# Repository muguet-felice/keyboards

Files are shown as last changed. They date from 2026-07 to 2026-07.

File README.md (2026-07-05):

# Muguet Keyboards

Firmware, source files, and documentation for Muguet keyboard projects.

## Repository structure

Each product is stored in its own folder.

Typical contents are:

- `firmware/`  
  Prebuilt firmware files.

- `source/`  
  QMK / Vial source files.

- `README.md`  
  Product-specific information.

- Setup guide PDF  
  Assembly and setup guide.

## Notes

Firmware files are intended for the products and configurations described in each product folder.

Unsupported microcontrollers, modified hardware, custom builds, and modified firmware are not officially supported.

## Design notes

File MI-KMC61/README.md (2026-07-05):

# MI-KMC61

MI-KMC61 is a 6-key macro keyboard by Muguet.

## Files

- `MI-KMC61_SetupGuide.pdf`  
  Setup guide and assembly manual.

- `QuickStart.pdf`  
  Package insert note / quick start notice.

- `firmware/`  
  Prebuilt firmware files.

- `source/`  
  QMK / Vial source files.

## Firmware

Use the latest `.hex` file in the `firmware` folder.

## Notes

This product is a DIY keyboard kit.  
Please read the setup guide before assembly, use, or firmware update.

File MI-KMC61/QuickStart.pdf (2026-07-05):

© Muguet
2026-01 版

## 6 キーマクロキーボード

# MI-KMC61

この度は本製品をお買い求めいただき、ありがとうございます。 本製品にはセットアップガイドを同封しておりません。お手数ですが、組み立てにあたり以下のサイトから、最新版の

セットアップガイドをダウンロードしてください。

GitHub：

https://github.com/muguet-felice/keyboards/tree/main/MI-KMC61

MI-KMC61_SetupGuide.pdf
最新版は上記ファイル名で公開しております。

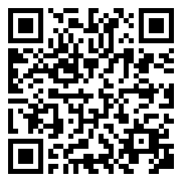
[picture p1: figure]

※本製品の組み立てにあたり、以下を別途ご用意ください。

・キーキャップ 6 個

・キースイッチ 6 個

いずれも、Cherry MX 互換のものをご用意ください

※本製品の組み立てには、以下の各種工具が必要です。
はんだ、はんだごて（電子部品向けの温度調整式のものを推奨） ニッパー（金属用）

プラスドライバー（No.1 または No.2 が適しています） キープラー（キースイッチ、キーキャップを外す場合のみ必要）

※本製品添付の Pro Micro は、ファームウェア書き込み済みです。

出荷時のファームウェアバージョンは 1.00 です。

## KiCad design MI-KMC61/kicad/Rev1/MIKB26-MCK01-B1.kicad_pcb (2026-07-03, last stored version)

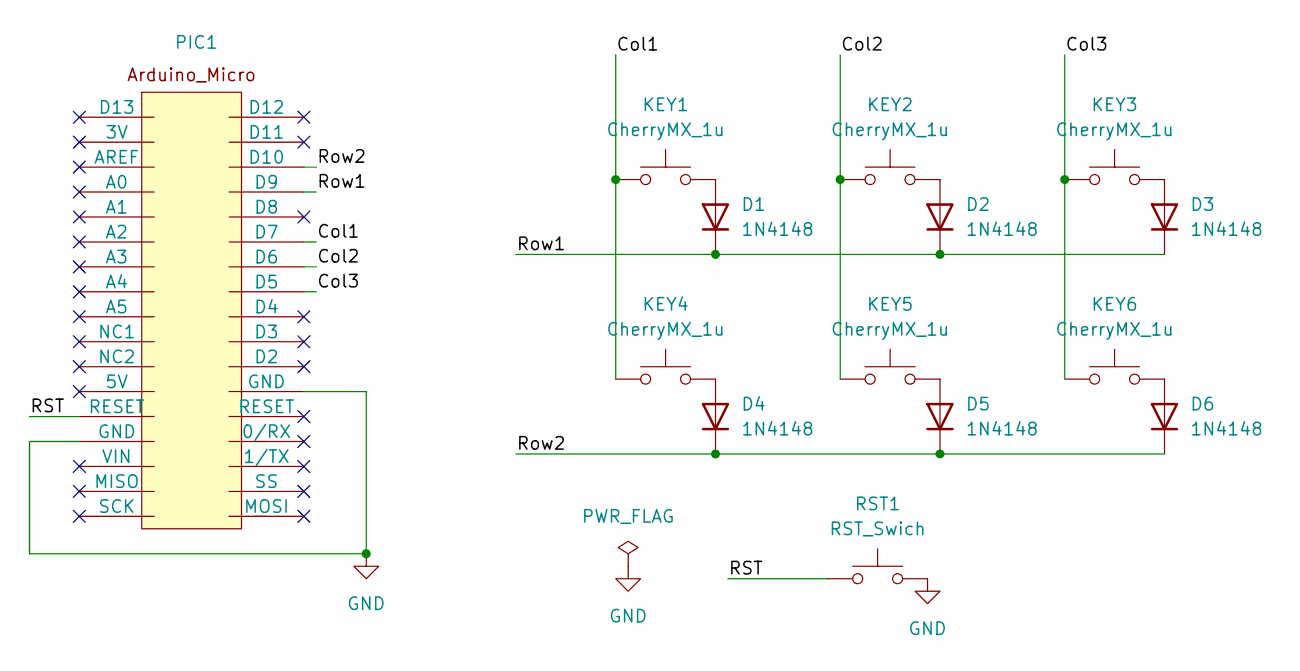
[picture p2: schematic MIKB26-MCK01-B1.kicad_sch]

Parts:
D1, D2, D3, D4, D5, D6: 1N4148; D_DO-35_SOD27_P7.62mm_Horizontal
KEY1, KEY2, KEY3, KEY4, KEY5, KEY6: CherryMX_1u; CherryMX_Solder_1u
PIC1: Arduino_Micro
RST1: RST_Swich; SW_PUSH_6mm

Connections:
/Col1: KEY1.2, KEY4.2, PIC1.D7
/Col2: KEY2.2, KEY5.2, PIC1.D6
/Col3: KEY3.2, KEY6.2, PIC1.D5
/RST: PIC1.RESET, RST1.1
/Row1: D1.1 (K), D2.1 (K), D3.1 (K), PIC1.D9
/Row2: D4.1 (K), D5.1 (K), D6.1 (K), PIC1.D10
GND: PIC1.GND, RST1.2
unnamed: D1.2 (A), KEY1.1
unnamed: D2.2 (A), KEY2.1
unnamed: D3.2 (A), KEY3.1
unnamed: D4.2 (A), KEY4.1
unnamed: D5.2 (A), KEY5.1
unnamed: D6.2 (A), KEY6.1

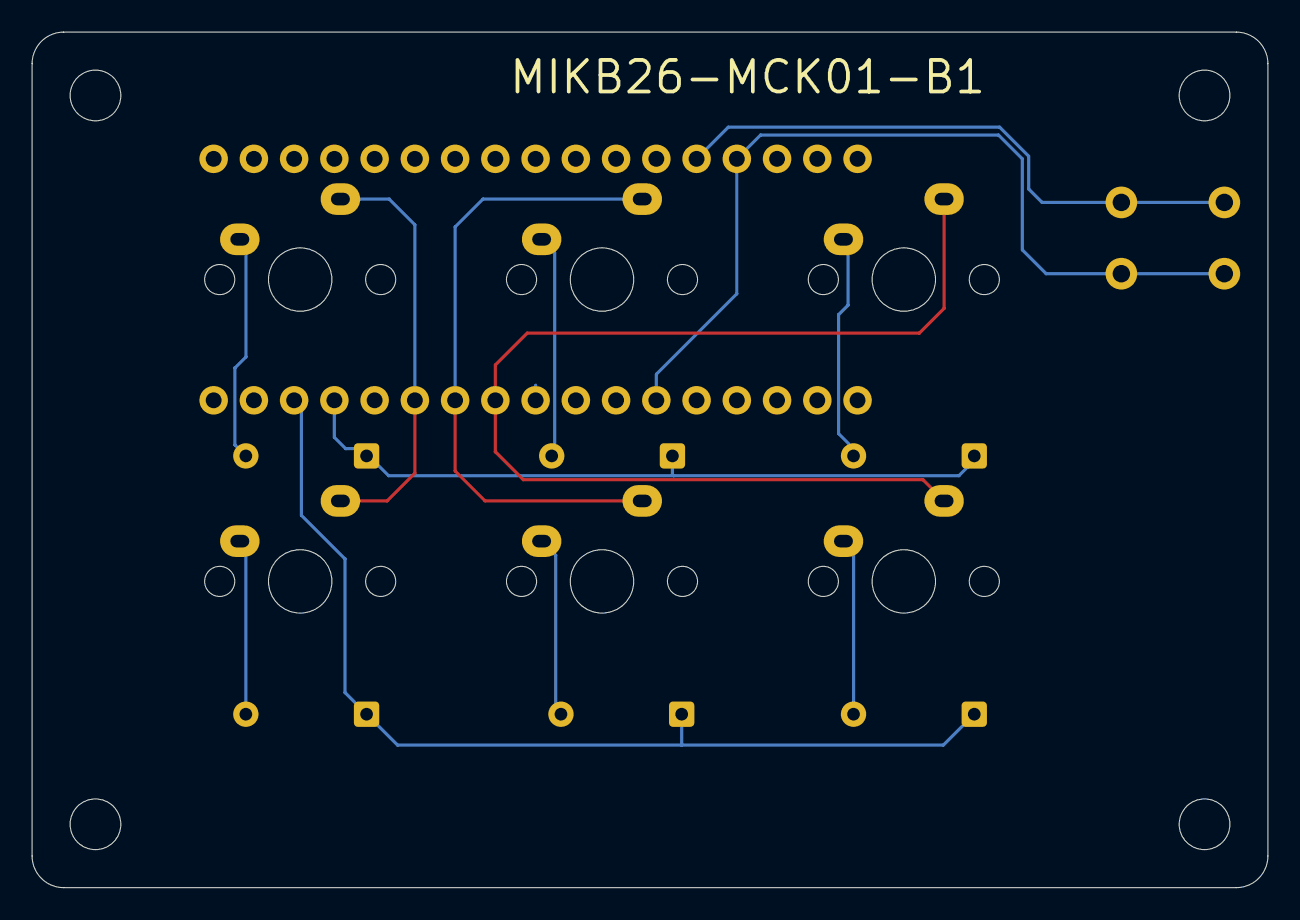
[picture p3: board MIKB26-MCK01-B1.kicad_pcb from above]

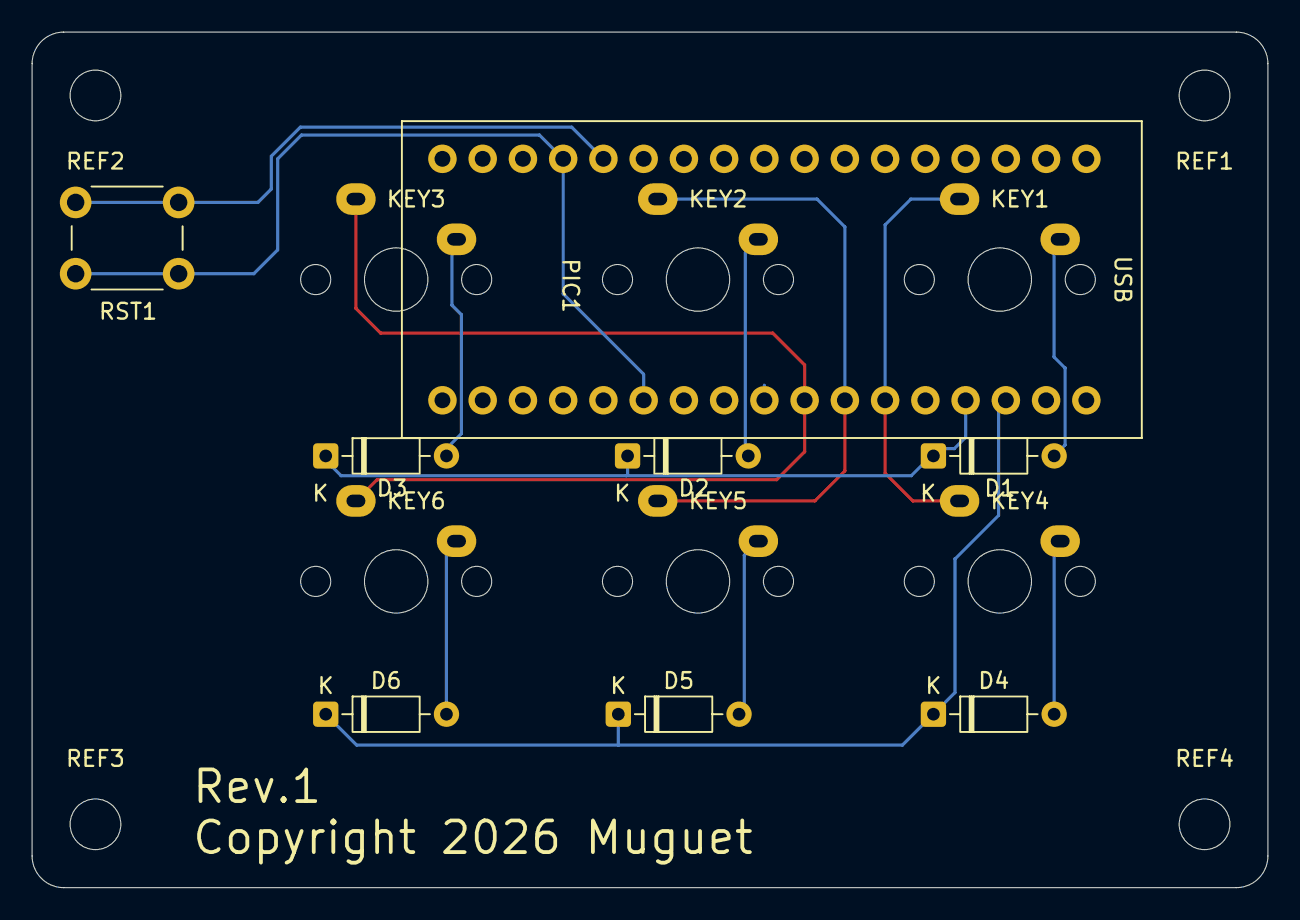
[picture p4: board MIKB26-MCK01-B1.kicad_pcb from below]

Board: 2 copper layers, 78.0 x 54.0 mm, 18 parts (8 on the bottom side), 13 nets.

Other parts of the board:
REF1, REF2, REF3, REF4: MountingHole_3.2mm_M3

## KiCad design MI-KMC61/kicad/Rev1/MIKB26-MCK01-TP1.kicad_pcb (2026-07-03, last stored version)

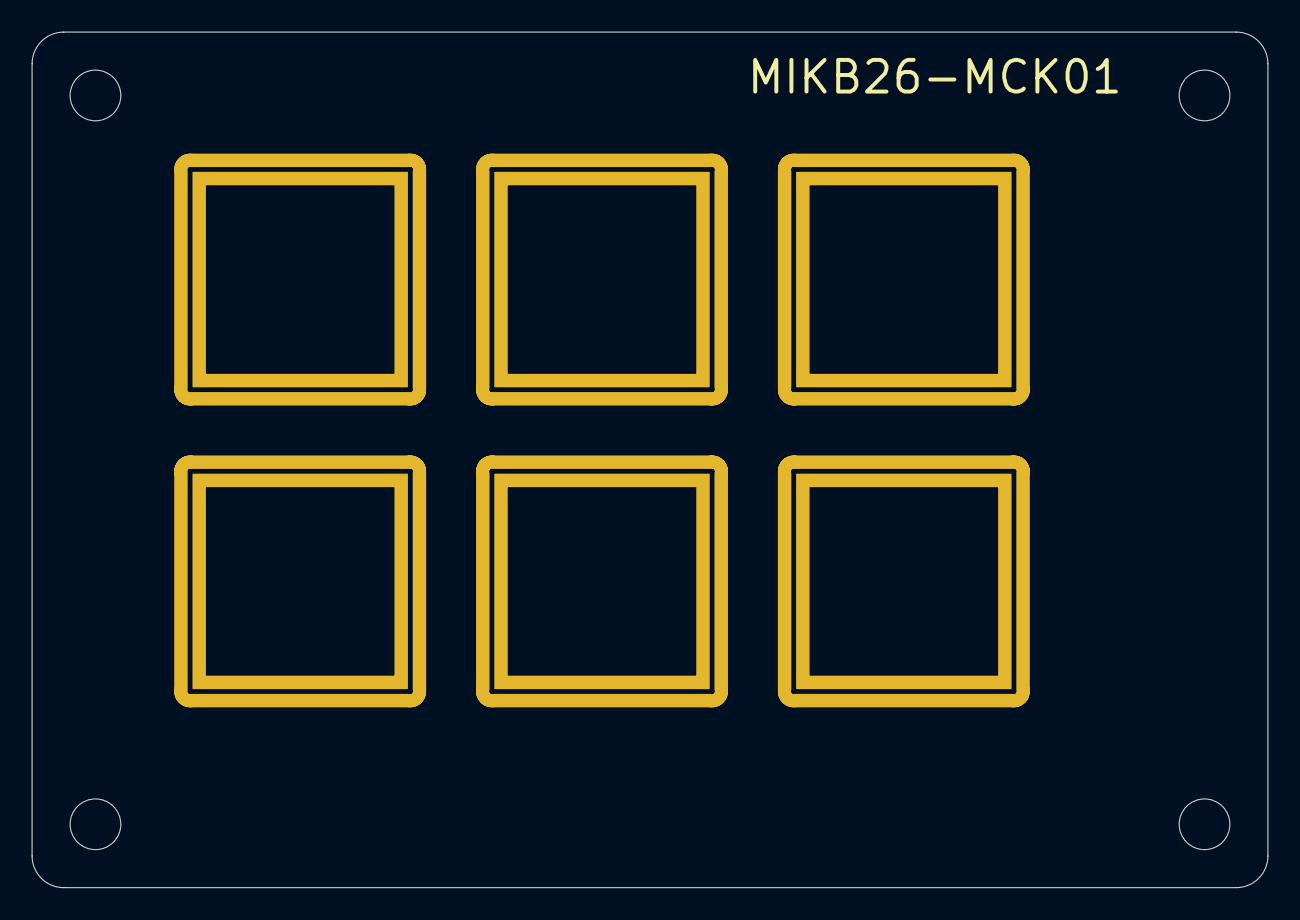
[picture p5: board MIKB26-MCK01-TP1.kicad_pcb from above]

Board: 2 copper layers, 78.0 x 54.0 mm, 10 parts (0 on the bottom side), 3 nets, no tracks yet.

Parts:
KEY1, KEY2, KEY3, KEY4, KEY5, KEY6: CherryMX_1u; SW_Hole_TH_1u
REF1, REF2, REF3, REF4: MountingHole_3.2mm_M3

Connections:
/Col1: KEY1.1 (2_2), KEY4.1 (2_2)
/Col2: KEY2.1 (2_2), KEY5.1 (2_2)
/Col3: KEY3.1 (2_2), KEY6.1 (2_2)

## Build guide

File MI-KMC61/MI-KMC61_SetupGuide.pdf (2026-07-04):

© Muguet
2026-01 版

## 6 キーマクロキーボード

# MI-KMC61

# セットアップガイド

この度は本製品をお買い求めいただき、ありがとうございます。 組み立ての前に、本セットアップガイドをよくご確認ください。 作業中も必要に応じて参照しながら、手順に沿って組み立てを進めてください。 本セットアップガイドは組み立て後も確認できるよう、お手元に保管してください。

【ご使用上の注意】
本製品は、一般的な PC 用入力機器としての個人利用を想定して設計されています。 医療、航空宇宙、運輸、軍事など、高い安全性・信頼性が要求される用途ではご使用いただけません。

本製品は、ユーザーご自身で組み立てを行うキット製品です。 組み立ての際は、本セットアップガイドをよく確認し、部品の向きや取り付け位置を間違えないよう注意し

て作業してください。

はんだ付け不良、部品の取り付け間違い、ショート、組み立て作業中の部品破損など、ユーザー作業に起 因する不具合については、原則としてサポート対象外となります。

ファームウェア更新、キーアサイン変更、マイコン交換、改造、指定外部品の使用、外部ソフトウェア・外部 サービスの利用に起因する不具合については、対応できない場合があります。

また、本製品に関連して生じたいかなる損害についても、当方は責任を負いかねます。 あらかじめご了承ください。

## 【もくじ】

## セットアップする

Step１ 付属品を確認する

Step２ 組み立てる

Step３ キーアサインを変更する

付録

ファームウェアをアップデートする

マイコンを Type-C タイプに変更する際のご注意

本製品で使える Vial®の機能

# セットアップする

## Step１ 付属品を確認する

本製品には以下の部品が付属しています。

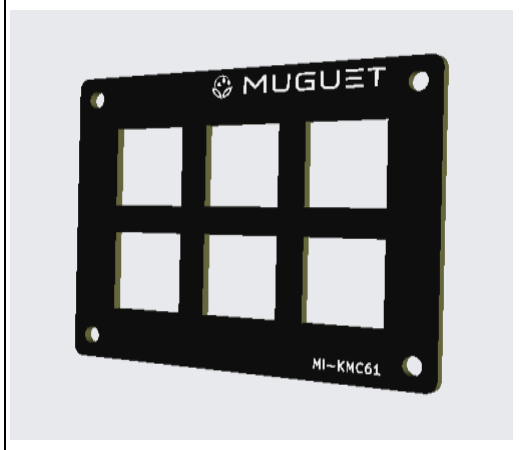
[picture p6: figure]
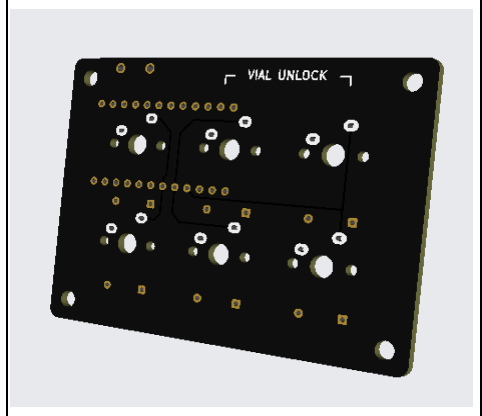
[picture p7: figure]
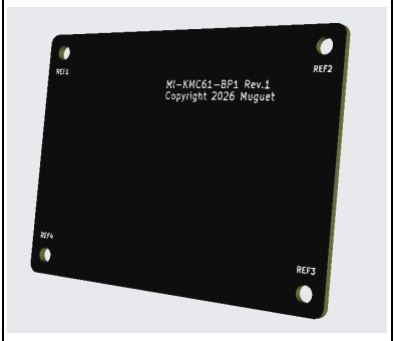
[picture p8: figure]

部品袋開封前に、すべての部品が揃っていることを確認してください。 ※部品袋開封後、または組み立て作業開始後の部品不足・破損については対応いたしかねます。
トッププレート 1 枚 | メインボード 1 枚 | ボトムプレート 1 枚

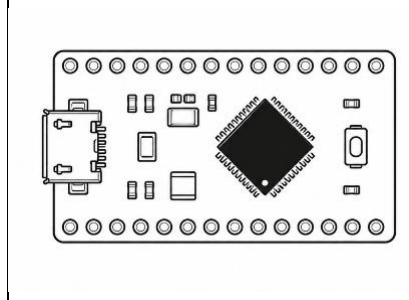
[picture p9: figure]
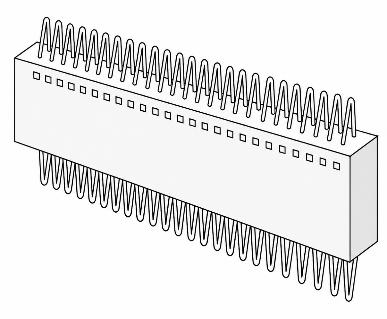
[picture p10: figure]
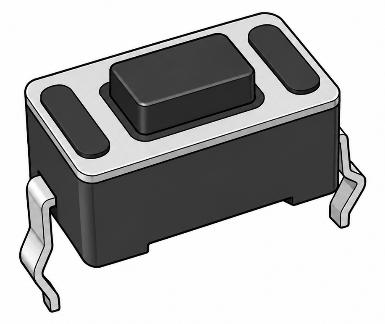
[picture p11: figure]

Pro Micro マイコン 1 枚 本セットには Type-C が同梱され ています | コンスルー 2 本 | リセットスイッチ 1 個
ネジ 10mm 4 本 5mm ４本 | 六角スペーサー 4 個 | ナイロンスペーサー 4 個

ダイオード ６本 | ゴム足 4 個 1 シート

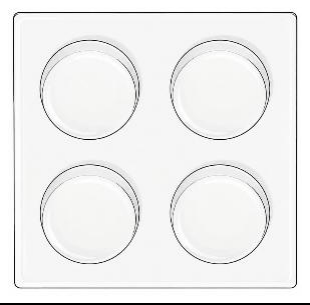
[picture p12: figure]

※上記のほかに以下が別途必要になります

・キーキャップ 6 個

・キースイッチ 6 個

いずれも、Cherry MX 互換のものをご用意ください

遊舎工房、Amazon などの EC サイトで入手可能です。お好みのタッチ、レスポンスのものをお選びくだ

さい。

※本製品の組み立てには、以下の各種工具が必要です。
はんだ、はんだごて
電子部品向けの温度調整式のものを推奨します。
温度は使用するはんだに合わせて調整してください。
ニッパー（金属用）

プラスドライバー（No.1 または No.2 が適しています）

キープラー
必須ではありませんが、キースイッチ、キーキャップを外す場合には必要になります。

【注意】はんだごてやニッパーなどによる火傷や怪我、小さなお子様による部品の誤飲などにご注意ください。 作業中に生じた火傷や怪我等について、当方は責任を負いかねます。

## Step２ 組み立てる

部品が一通りそろっていることを確認できたら、以下の手順に沿って組み立ててください。

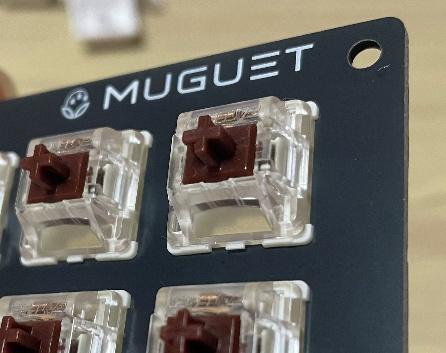
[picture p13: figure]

① トッププレートにキースイッチをはめ込む
トッププレートの表から、キースイッチを取り付けます。この時、 のロゴマークが正しく見える向きに上
下を合わせてください。
本製品では、すべてのキースイッチを同じ向き（裏面のピンが 上側）になるように取り付けてください。

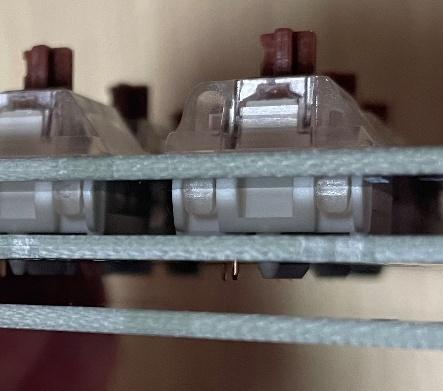
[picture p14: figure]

② 仮組して、正しく組みあがることを確認する
メインボードを、トッププレートの裏側から合わせてください。

このとき、四隅のねじ穴についている REF 番号が、すべての基 板で同じ位置になるようにしてください。
キースイッチの突起部分やピンが、メインボードの穴に正しくは まることを確認してください。確認ができたら、メインボードの表 裏、上下を把握しておいてください。

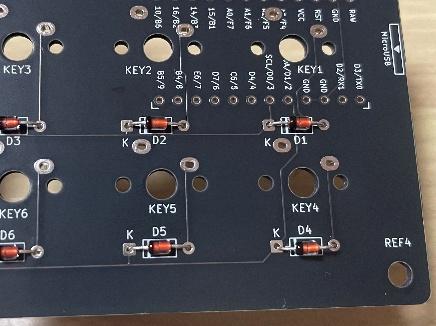
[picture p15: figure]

③ ダイオードを取り付ける
メインボードの裏面に、印字に従ってダイオードを取り付けま す。
ダイオードの黒い帯がある側を、メインボード上の K 印字側に 向けて取り付けます。
ダイオードはメインボードの裏面から取り付け、表面に飛び出し たリード線をはんだ付けしてください。はんだ付け後は飛び出し

たリード線をニッパーで短くカットしてください。

④ リセットスイッチを取り付ける
リセットスイッチを、ダイオード同様メインボードの裏面に取り付

けてください。
根本までしっかり、基板に押し付けるように差し込んでから、 はんだ付けしてください。

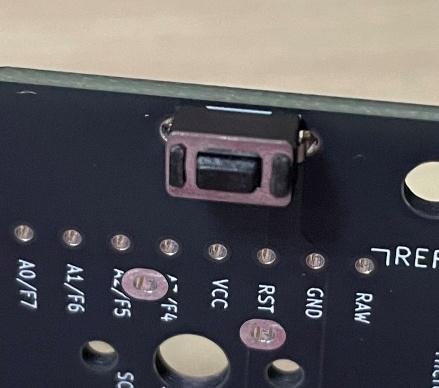
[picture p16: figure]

⑤ はんだ付けが漏れていないか、確認する
ここまでに取り付けた部品について、はんだ付け漏れがないことを確認してください。 また、ダイオードの取り付けが正しい事（黒い帯の部分が K と書かれた端子の方に向いているこ と）を確認してください。
【注意】以降の手順で、トッププレートを取り付けた後は、はんだ付けのやり直しが非常に難しくなり ます。

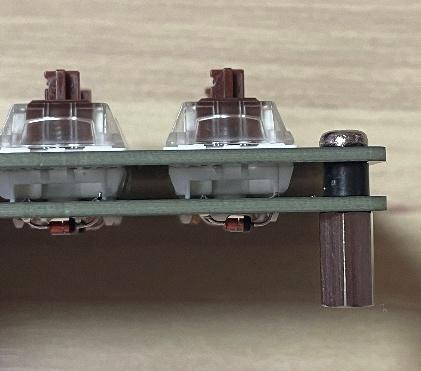
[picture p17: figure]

⑥ トッププレートを取り付ける
トッププレートを②で確認した通りにキースイッチごとメインボード に組み合わせてください。キースイッチが正しくメインボードに組

み合わさった状態で、四隅を 10mm ネジと六角スペーサーで 固定します。

この際、トッププレートとメインボードの間に、四隅のネジ穴部 分にナイロンスペーサーを合わせ、ナイロンスペーサーをネジが貫 通するようにしてください。

⑦ キースイッチをはんだ付けする

メインボード裏面から、キースイッチの金属端子をすべて、はんだ付けしてください。

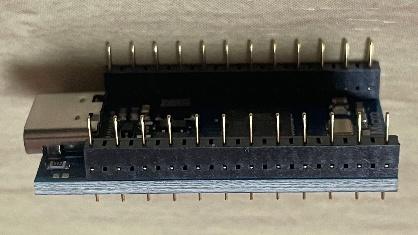
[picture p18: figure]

⑧ コンスルーを Pro Micro に取り付ける

コンスルーを Pro Micro の表側に取り付けてください。取り付

けの際は、コンスルーのプラスチック部分の側面に見える窓

が、Pro Micro 側になるようにしてください。また、窓の向きが 2 本とも同じ向きになるように取り付けてください（写真参 照）

コンスルーは Pro Micro にはんだ付けしてください。

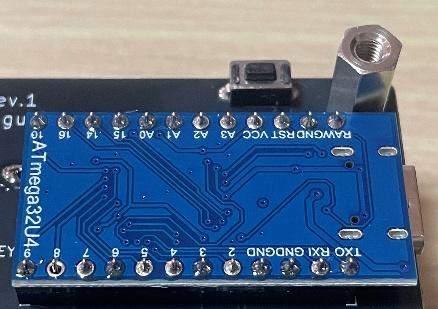
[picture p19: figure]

⑨ Pro Micro を取り付ける

メインボードに Pro Micro を根元までしっかり差し込んでくださ

い。
USB 差込口がメインボード側、かつ、メインボードの外に向くよ うに取り付けます。

Pro Micro は差し込むだけで、コンスルーのバネの力で固定さ れます。
メインボードとコンスルーははんだ付けしないでください。

⑩ ボトムプレートを取り付ける
ボトムプレートの四隅のネジ穴を六角スペーサーに合わせ、

5mm ネジで取り付けてください。
ボトムプレートは型番印字のある面をメインボード側に向けて 取り付けます。

また、各ネジ穴の REF1～REF4 の印字が、メインボード側の 印字位置と一致するように取り付けます。

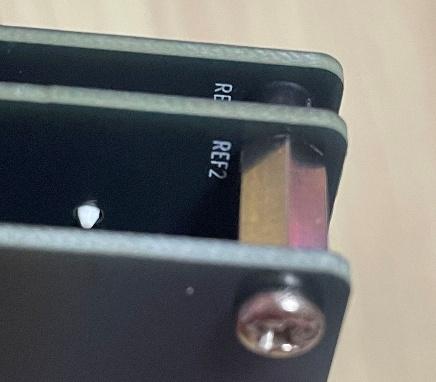
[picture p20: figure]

⑪ USB ケーブルで PC 本体と接続してください。USB ケーブルは USB 規格 2.0 以上のデータ通信がで きるものが必要です。
【注意】充電専用ケーブルでは動作しません。
テキストエディタなどを開き、すべてのキーを順に押下して、正常に動作することを確認してください。

デフォルトのキーアサインは、「Step３ キーアサインを変更する」をご確認ください。

## Step３ キーアサインを変更する

デフォルトのキー配置は以下のようになっています。

本製品は Vial®に対応しています。

Vial®の Web 版設定ツールを使用することで、キーアサインの変更をブラウザ上で行うことができます。 ※変更したキーアサインは本製品の Pro Micro 内に保存されます。 設定変更後に通常使用する際は、インターネットや Vial®サイトへの接続は不要です。

Vial®を使ったキーアサインの変更は以下の手順で行います。

① Vial®に接続する
キーボードを接続した PC でブラウザを開き、以下の URL に接続します。

https://vial.rocks/

「Start Vial」という大きなボタンが表示されれば成功です。

② キーボードを選択する

Start Vial ボタンをクリックすると、キーボードデバイスリストが表示されます。

本製品の場合、「MI-KMC61」を選択し、「接続」をクリックしてください。

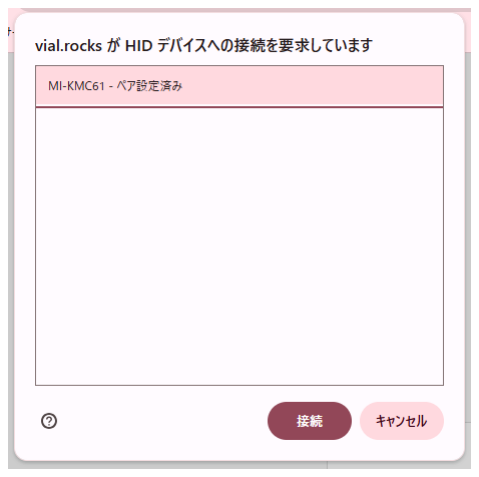
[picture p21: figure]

③ キーアサインを変更する
現在のキーアサインが表示されます。

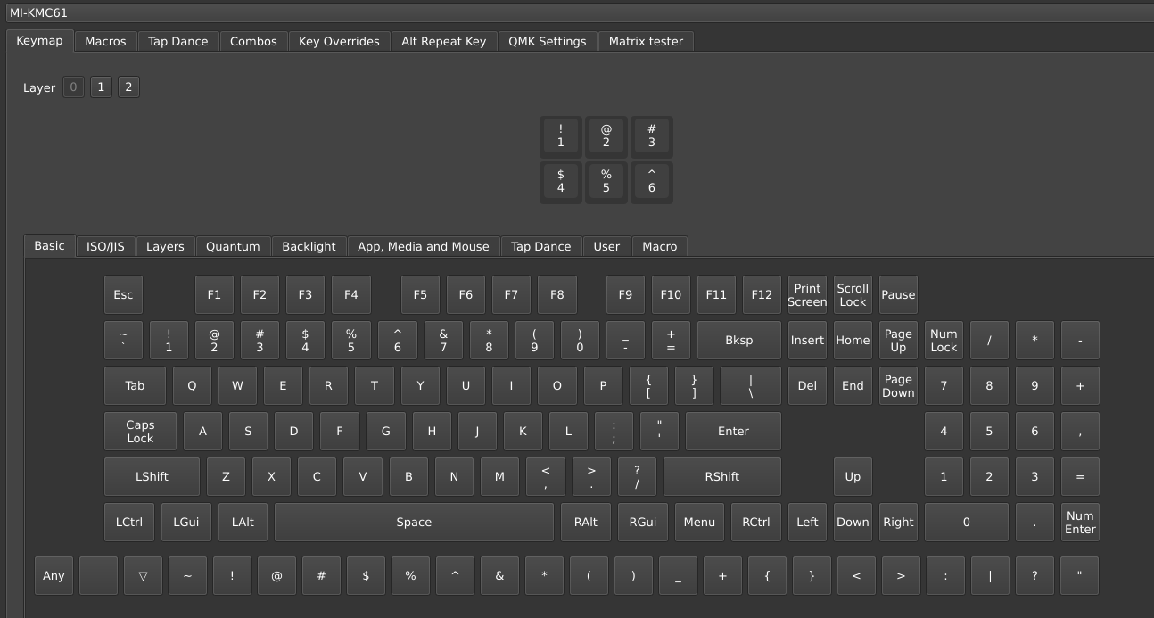
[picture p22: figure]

キーアサインを変更する場合は、変更したいキーを選択し、下部のキーリストから対応するキーを選んで

ください。

④ Vial®ロックを解除する
※マクロなど一部の機能は、誤操作による設定変更を防ぐため、設定変更時に Vial®上でロック解除が 求められる場合があります。

この場合は、画面に表示された 2 つのキーを押しっぱなしにしてください。 ダイアログ下部のインジケータがいっぱいになり、画面表示が消えるまで押したままにしてください。

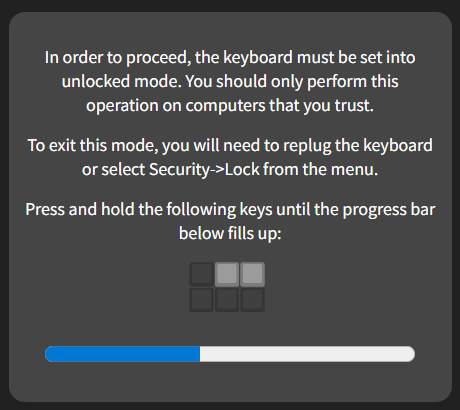
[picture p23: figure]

（メインボードにも、対象のキーが印字されていますので、上下反転で使用している際は印字を参考にして ください）

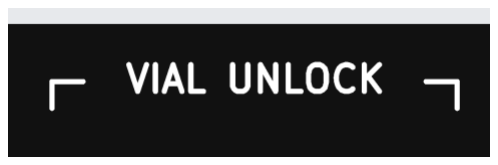
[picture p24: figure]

※Vial®の詳細な使い方、設定方法、機能については、インターネットサイト等の情報をご参照ください。 お問合せいただいても、回答いたしかねます。

付録

## ファームウェアをアップデートする

Vial®の仕様変更や不具合対応などにより、ファームウェアのアップデートが必要になる場合があります。

【注意】ファームウェアを書き込むと、ユーザーが設定したキーアサインが初期化される場合があります。 現在のキーアサインや重要なマクロなどは、あらかじめメモしておいてください。 【注意】ファームウェアのアップデートは、手順を確認したうえで慎重に行ってください。 万が一アップデートに失敗した場合でも、当方は責任を負いかねます。

※ファームウェアをアップデートする際は、以下のソフトウェアが別途必要になります。

・QMK Toolbox
ファームウェアを Pro Micro マイコンに書き込むためのソフトウェアです。

ファームウェアのアップデートは以下の手順で行います。

① ファームウェアダウンロード

GitHub の以下のリンクから、最新のファームウェアをダウンロードしてください。

https://github.com/muguet-felice/keyboards/tree/main/MI-KMC61/firmware※muguet_MI-KMC61_firmware.hex をダウンロードしてください

② 書き込むファームウェアを指定する

QMK Toolbox を起動します。

「Open」ボタンを押下し、①でダウンロードしたファームウェア（.hex ファイル）を開きます。

「Local file」欄に、指定したファームウェアファイルが表示されていることを確認してください。

③ ファームウェアを書き込む

「Auto-Flash」にチェックが入っていることを確認してください。
本製品を USB に接続し、リセットボタンを素早く 2 回押下してください。

QMK Toolbox の画面に、device connected の文字が表示され、自動的にファームウェアが更新さ れます。

「device disconnected」と表示されるまで放置してください。

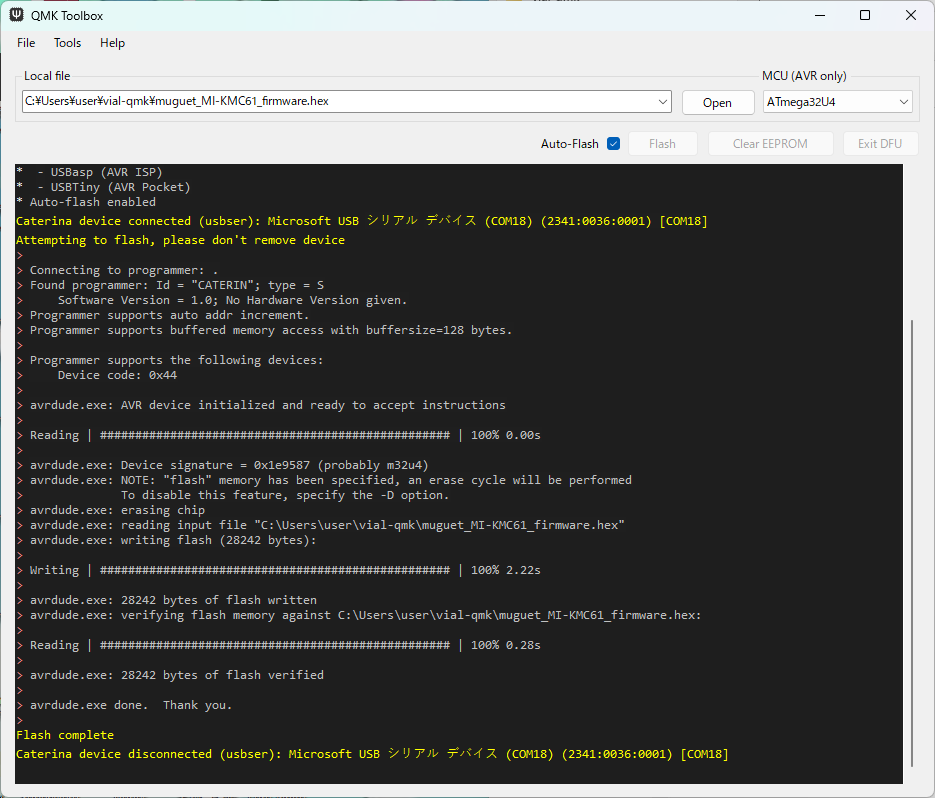
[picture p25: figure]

【注意】ファームウェア更新中にデバイスを抜いたり、PC の電源を切ったり、QMK Toolbox を終了した

りしないでください。最悪の場合、Pro Micro マイコンを破損する恐れがあります。

④ 再接続する

書き込みが終われば、QMK Toolbox を終了した後、本製品の USB をいったん抜いて差しなおしてく

ださい。
問題なければ、自動的に OS がハードウェアを認識して、使用可能になります。

## マイコンを Micro-B タイプに変更する際のご注意

本製品に付属の Pro Micro マイコンは Type-C タイプとなっております。

Pro Micro の Micro-B タイプをご用意いただくことで、Micro-B の USB ケーブルでもご利用いただくことが 可能です。

※Pro Micro の変更は、ユーザーの自己責任で行ってください。当方ではサポート、不具合対応のいずれ も致しかねます。
【注意】Micro-B タイプに変更した場合、ケーブルの差し込み口がやや奥になります。 【注意】変更される場合は、必ず、以下の規格を満たす Pro Micro をご用意ください

・仕様：Pro Micro 互換

・電源：5V/16MHz

・MCU：ATmega32U4
・ピンレイアウトが製品添付品と同一であること

Pro Micro マイコンにファームウェアを書き込む手順は、「ファームウェアをアップデートする」をご参照ください。

## 本製品で使える Vial®の機能

本製品は、Vial®の以下の機能に対応しています。

・6 キーロールオーバー
最大 6 キーまでの同時押下に対応しています。

・マクロ
複数のキーを指定した順番に押下する機能です

・レイヤー
レイヤーを切り替えることで、キーアサインを変更し、必要に応じて使い分けることができるようになります。 本製品では最大 3 レイヤーに対応しています。

・マウスキー
キーボードだけでマウスカーソルの移動やクリックなどの操作を可能とします。

・タップダンス
1 つのキーを押す回数や押し方に応じて、異なるキー入力を割り当てる機能です。

※個別のキー設定や、Vial®の各種機能に関するお問い合わせには対応いたしかねます。 あらかじめご了承ください。

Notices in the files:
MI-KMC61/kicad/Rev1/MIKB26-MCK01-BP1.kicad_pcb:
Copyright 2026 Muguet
